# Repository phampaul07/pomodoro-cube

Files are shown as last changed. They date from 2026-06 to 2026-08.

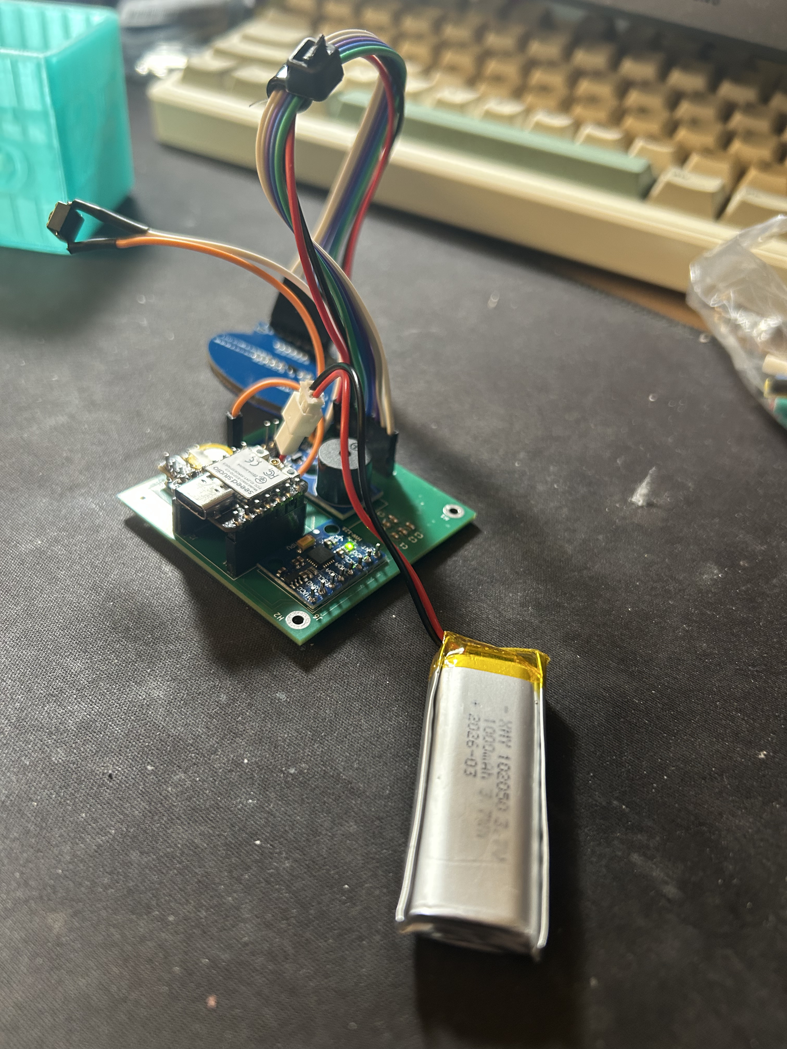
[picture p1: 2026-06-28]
images/components.jpg

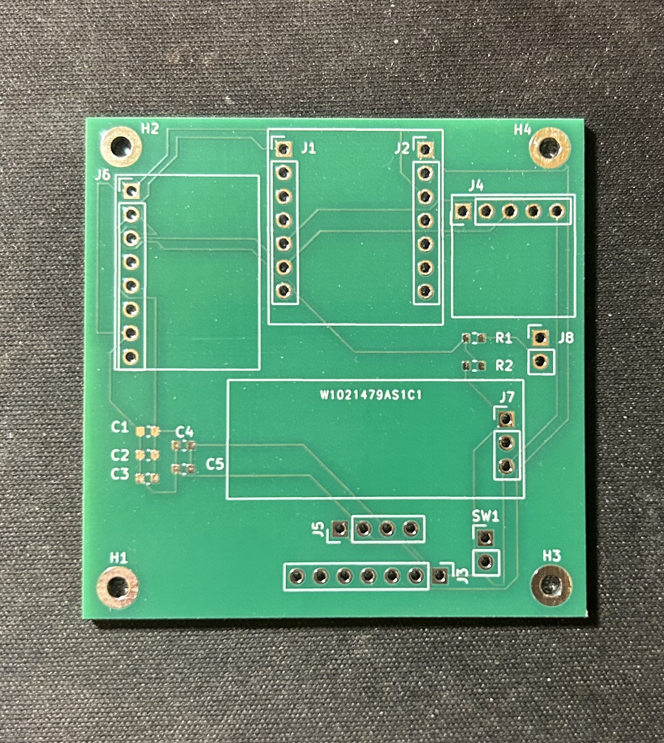
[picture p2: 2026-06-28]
images/front_pcb.jpg

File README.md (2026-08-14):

<h1 align="center"> Smart Pomodoro Cube</h1>

<h3 align="center">
A fully custom embedded productivity cube featuring a Pomodoro timer, digital clock, virtual pet, productivity tracker, and magnetic charging dock.
</h3>

<p align="center">
CircuitPython • ESP32-C3 • Embedded Systems • CAD • 3D Printing • Analog Electronics • KiCad
</p>

<p align="center">
  
</p>

---

# README Contents
- [Overview](#overview)
- [Demonstrations](#demonstrations)
- [Features](#features)
- [Hardware](#hardware)
- [Getting Started](#getting-started)
- [Mechanical Design](#mechanical-design)
- [Engineering Deep Dive](#engineering-deep-dive)
- [Software Highlights](#software-highlights)
- [Challenges](#challenges)
- [Lessons Learned](#lessons-learned)
- [Future Improvements](#future-improvements)
- [Gallery](#gallery)
- [Acknowledgements](#acknowledgements)
- [Contact](#contact)

---

# Overview

The Smart Pomodoro Cube is a handheld productivity device that combines embedded systems, hardware engineering, and industrial design into a compact form factor no larger than a standard Rubik's Cube.

Instead of navigating through menus or using a touchscreen, the cube uses its physical orientation to select timer durations. Once docked onto its custom magnetic charging station, it transforms into an entirely different interface featuring an interactive virtual pet, productivity tracker, and quick-access study tools.

Every major component—including the enclosure, charging dock, firmware, custom KiCad PCB, and user interface—was designed specifically for this project.

The goal was not only to create a useful studying companion, but also to explore embedded systems, custom electronics, CAD, and hardware-software integration while fitting everything inside an extremely limited volume.

---

# Demonstrations

The Pomodoro Cube has two primary modes of operation.

---

## Standalone Cube

<p align="center">
<a href="https://youtube.com/shorts/b-1S72bGzG8?feature=share">

</a>
</p>

<p align="center">
<b>Click the thumbnail above to watch the standalone demonstration.</b>
</p>

### Demonstrated Features

- Real-time clock
- Battery percentage
- Temperature monitoring
- Cube orientation timer selection
- Pause / Resume
- Timer reset
- Countdown progress bar
- Portable battery operation

---

## Interactive Charging Dock

<p align="center">
<a href="https://youtube.com/shorts/HYNcFR9NDS4?feature=share">

</a>
</p>

<p align="center">
<b>Click the thumbnail above to watch the dock demonstration.</b>
</p>

### Demonstrated Features

- Magnetic docking
- Automatic dock detection
- Charging indicator
- Clock Mode
- 15-minute Quick Timer
- Interactive Tamagotchi Pet
- Petting animation
- Productivity Stats

---

# Features

## Digital Clock

When idle, the cube functions as a portable desk clock displaying:

- Current time
- Battery percentage
- Temperature
- Charging status

using an external RTC module and onboard sensors.

---

## Pomodoro Timer

The cube's primary function is a distraction-free Pomodoro timer.

Simply rotate the cube onto one of its faces to instantly choose a timer duration.

Features include:

- Multiple timer durations
- Pause / Resume
- Reset
- Bar progress visualization
- Completion notification via beeps
- Battery-powered portability

---

## Magnetic Charging Dock

One of the biggest design goals was eliminating cables during normal use.

The cube charges magnetically using pogo pins while simultaneously detecting dock states and reading dock button presses. 

The charging dock was hand-built using a custom perfboard and soldered circuitry, while the internal electronics of the cube itself are mounted on a custom-designed PCB routed in KiCad.

---

## Dock Modes

Docking the cube unlocks four additional operating modes.

### Clock

Displays the standard clock while charging.

---

### Quick Timer

Instantly adds study time in 15-minute increments without rotating the cube.

---

### Tamagotchi

An interactive Tamagotchi-inspired virtual pet.

Features include:

- Idle animations
- Random blinking
- Petting animation
- Smooth sprite animation
- Physical interaction using dock buttons

---

### Productivity Statistics

Tracks long-term study habits including:

- Daily focus time
- Focus sessions
- Daily streak
- Lifetime sessions

---

# Hardware

| Component | Purpose |
|---|---|
| Seeed Studio XIAO ESP32-C3 | Main Microcontroller |
| Custom KiCad PCB | Main Board / Cube Electronics |
| 1.28" Round GC9A01 IPS Display | User Interface |
| MPU6050 | Orientation Detection |
| RTC Module | Timekeeping |
| 3.7V LiPo Battery | Portable Power |
| Magnetic Pogo Pins | Charging & Communication |
| Custom Perfboard | Dock Electronics |

---

# Getting Started

This runs on CircuitPython rather than compiled firmware, so there's no build/flash toolchain — the board mounts as a USB drive and files are copied directly onto it.

1. Flash the [CircuitPython UF2](https://circuitpython.org/board/seeed_xiao_esp32c3/) for the Seeed Studio XIAO ESP32-C3 (hold BOOT while plugging in, drag the `.uf2` onto the `ESP32C3` drive).
2. Once it reboots into CircuitPython, it'll appear as a `CIRCUITPY` drive. Copy the entire `firmware/` folder's contents onto it: `code.py`, `animation.py`, `dock.py`, the `.bmp` sprite assets, and the `lib/` folder of vendored Adafruit libraries.
3. `code.py` is the entry point — CircuitPython auto-runs it on boot. `firmware/legacy/standalone_cube.py` is an earlier, dock-less iteration kept for reference only; it isn't used.
4. The board reloads automatically any time `code.py` is saved. [Thonny](https://thonny.org/) (or any serial-capable editor) works well for live editing and viewing the serial console.

---

# Mechanical Design

A major objective of this project was fitting an entire embedded system inside the volume of a standard Rubik's Cube.

This required careful consideration of:

- Internal component placement
- Custom PCB dimensions and mounting
- Cable routing
- Battery placement
- Display clearance
- Magnet positioning
- Dock alignment

---

# Engineering Deep Dive

## Analog Button Multiplexing

Because the magnetic pogo pin interface between the cube and the dock only has four physical connections (5V, GND, 3.3V, and a single data line), it was physically impossible to dedicate separate GPIO pins for each of the four dock buttons.

To overcome this hardware constraint, every dock interaction is transmitted through the single available analog pin using a resistor ladder. Each button routes current through a different resistor, producing a unique voltage.

The ESP32 reads this incoming voltage through its ADC and determines which button was pressed based on predefined threshold ranges.

```
Button 1 → Home Clock
Button 2 → Quick Timer
Button 3 → Tomo
Button 4 → Productivity Stats
```

---

## Battery Monitoring

A fully charged LiPo battery outputs approximately 4.2V, exceeding the ESP32's safe analog input voltage.

To safely monitor the battery, a voltage divider using two identical 10kΩ resistors cuts the voltage in half before it reaches the ADC.

Hardware Flow:
```
Battery
↓
Voltage Divider
↓
ESP32 ADC
```

Software Logic:
```
ADC Reading
↓
Measured Voltage
↓
×2
↓
Actual Battery Voltage
↓
Battery Percentage
```

This approach allows safe and accurate battery monitoring without risking damage to the microcontroller.



---

## Firmware Architecture

The firmware is built around a finite state machine.

```
Standalone
 └── Clock
      │
      ▼
    Timer

Docked
 └── Clock
      ├── Quick Timer
      ├── Tomo
      └── Productivity Stats
```

Separating functionality into individual states simplified transitions, animations, and memory management.

---

# Software Highlights

- CircuitPython firmware
- SPI-driven GC9A01 display
- TileGrid sprite animations
- Memory-efficient bitmap loading
- Real-time battery monitoring
- Dock state detection
- ADC signal filtering
- Finite State Machine architecture

---

# Challenges

This project introduced me to several engineering disciplines simultaneously.

## Mechanical

- First complete CAD enclosure
- Designing around extremely limited internal space
- Dock alignment tolerances

---

## Electrical

- Designing a custom PCB in KiCad for the cube's internal layout
- Designing analog resistor ladder circuits
- Designing a voltage divider
- Magnetic pogo-pin charging
- Battery management
- Dock signal integrity

---

## Embedded Software

- Memory optimization
- Bitmap management
- Animation timing
- Display flickering
- ADC calibration
- State machine architecture

---

## Debugging

Some of the most time-consuming issues included:

- ESP32 memory limitations
- Magnetic charging reliability
- Analog threshold calibration
- Battery percentage accuracy
- Dock signal filtering
- Sprite memory fragmentation

Many of these required custom diagnostic firmware, multimeter testing, and extensive trial-and-error before arriving at stable solutions.

---

# Lessons Learned

This project taught me far more than simply building a productivity timer.

Some of the biggest skills I developed include:

- Embedded Systems
- CircuitPython
- Analog Circuit Design
- PCB Design (KiCad)
- Hardware Debugging
- CAD
- 3D Printing
- Battery Management
- SPI Displays
- Embedded UI Design
- Firmware Optimization
- State Machine Architecture

---

# Future Improvements

Although the current prototype is fully functional, there are several improvements I would like to explore.

- Custom PCB for the charging dock to replace the perfboard prototype
- Improved magnetic charging reliability
- Lower-power sleep mode
- Configurable timer durations
- Improved charging dock alignment
- Historical productivity graphs
- Rotating screen animation to make the interface fixed

---

# Gallery

| Cube | Dock |
|---|---|
| |  |

| Real-Time Clock | Iterated Timer |
|---|---|
| |  |

| Tamagotchi | Stats |
|---|---|
| | |

| PCB | Wiring |
|---|---|
| front_pcb | components|

---

# Acknowledgements

This project was independently designed and built using CircuitPython on the Seeed Studio XIAO ESP32-C3.

It combines concepts from embedded systems, analog electronics, firmware development, mechanical design, PCB design, and human-centered interaction into a single portable productivity device.

---

# Contact

- **Paul Pham** — [phampp07@gmail.com](mailto:phampp07@gmail.com) • [linkedin.com/in/paul-pham07](https://www.linkedin.com/in/paul-pham07)

---

## If you enjoyed this project, consider leaving a star!

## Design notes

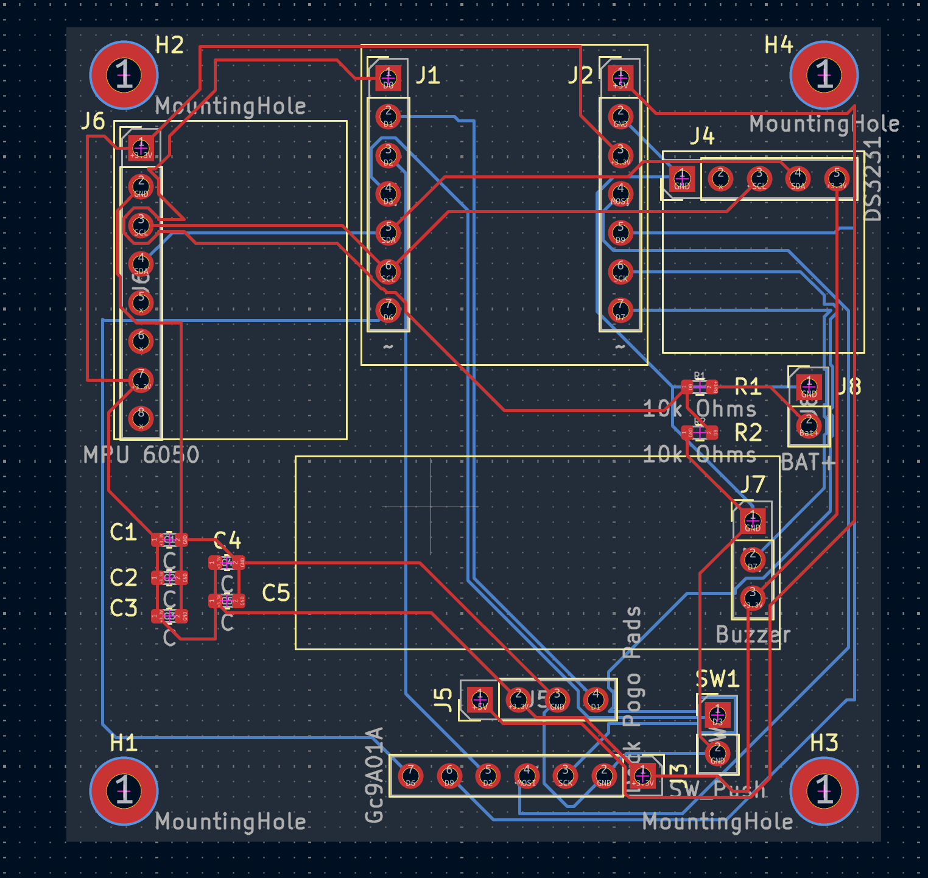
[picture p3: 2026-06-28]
images/hardware_design/pomodoro_pcb.png

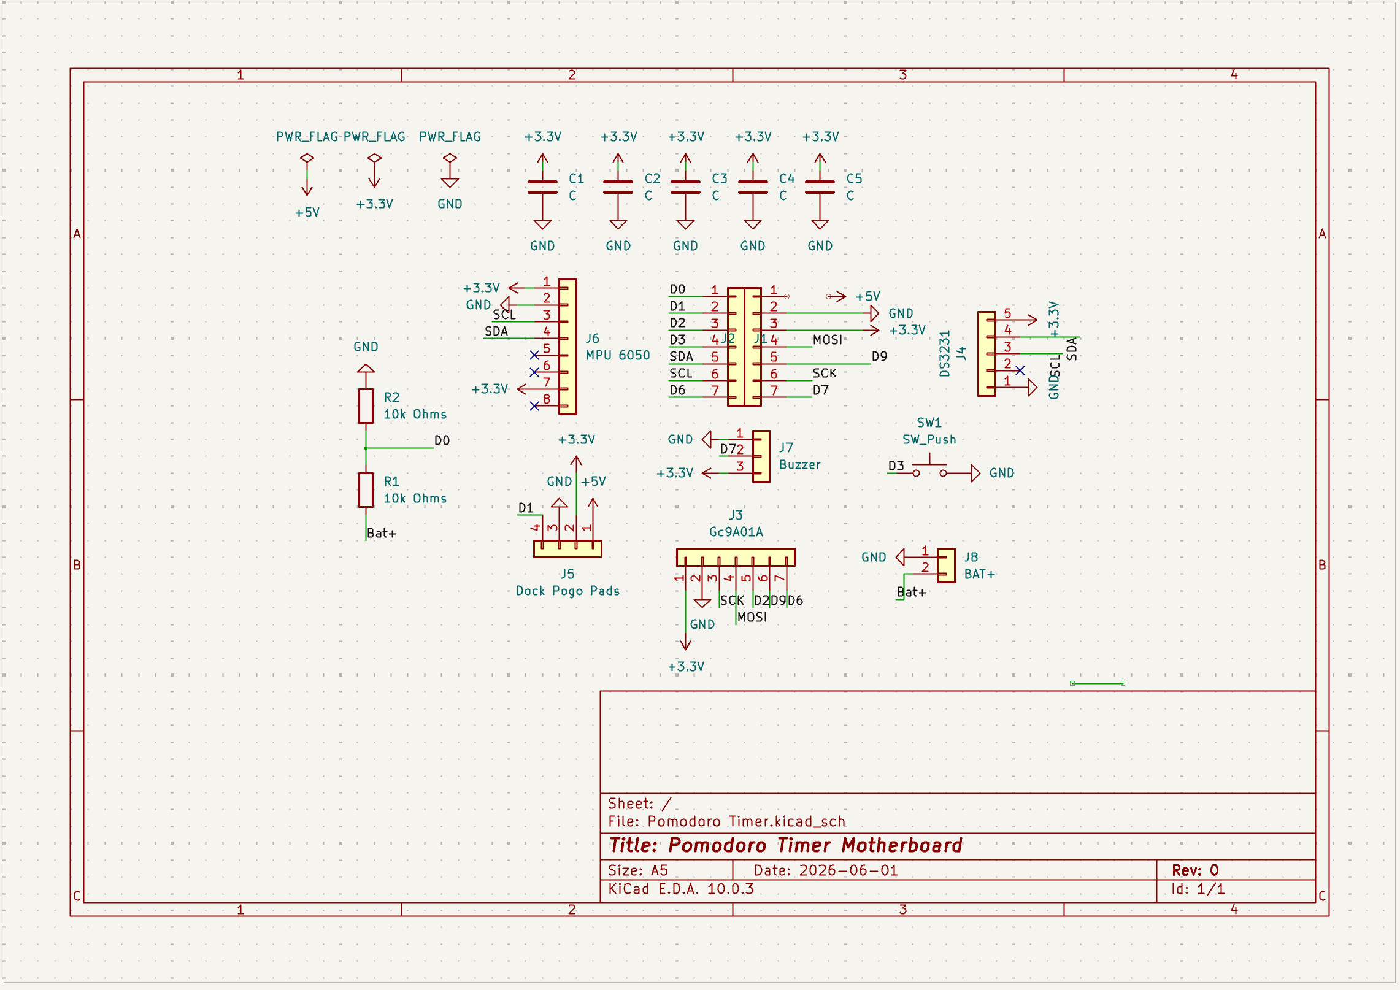
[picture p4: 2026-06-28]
images/hardware_design/pomodoro_schematic.png

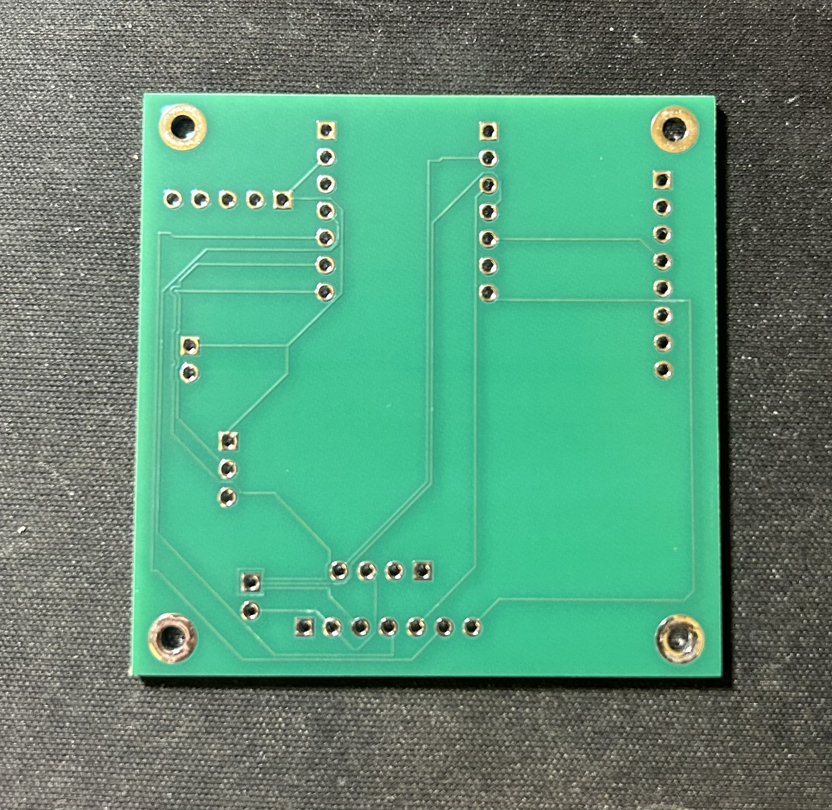
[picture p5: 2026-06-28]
images/back_pcb.jpg

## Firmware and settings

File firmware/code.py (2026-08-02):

import time
import board
import busio
import adafruit_mpu6050
import adafruit_ds3231
import digitalio
import terminalio
import displayio
import analogio
import fourwire
import alarm
import gc
import random
import microcontroller
import struct
from adafruit_gc9a01a import GC9A01A
from adafruit_display_text import label
from adafruit_display_shapes.rect import Rect
from adafruit_display_shapes.circle import Circle

# ------------------------------------------------------------
# 1. HARDWARE SETUP & INITIALIZATION
# ------------------------------------------------------------
FourWire = fourwire.FourWire
displayio.release_displays()

spi = busio.SPI(clock=board.D8, MOSI=board.D10)
battery_pin = analogio.AnalogIn(board.A0)
dock_pin = analogio.AnalogIn(board.A1)

tft_dc = board.D2
tft_cs = board.D9
tft_rst = board.D6

display_bus = FourWire(spi, command=tft_dc, chip_select=tft_cs, reset=tft_rst, baudrate=20000000)
display = GC9A01A(display_bus, width=240, height=240)
display.auto_refresh = False

i2c = busio.I2C(board.D5, board.D4)
mpu = adafruit_mpu6050.MPU6050(i2c, address=0x69)
rtc = adafruit_ds3231.DS3231(i2c)

button = digitalio.DigitalInOut(board.D3)
button.direction = digitalio.Direction.INPUT
button.pull = digitalio.Pull.UP 

buzzer = digitalio.DigitalInOut(board.D7)
buzzer.direction = digitalio.Direction.OUTPUT
buzzer.value = True

# ------------------------------------------------------------
# 2. STATE MEMORY VARIABLES
# ------------------------------------------------------------
mode_0 = "idle"
mode_1 = "5 minutes"
mode_2 = "25 minutes"
mode_3 = "45 minutes"
mode_4 = "60 minutes"
mode_5 = "finished"
mode_6 = "paused"
mode_7 = "reset"

time_duration = {
    mode_1: 300,
    mode_2: 1500,
    mode_3: 2700,
    mode_4: 3600
}

DOCKED_STATES = {"home", "timer", "tomo", "button_4", "dock_idle"}
MAX_INCREMENT_SECONDS = 99 * 60 + 59

orientation_buffer = []
buffer_size = 6

mode = mode_0 
previous_mode = mode_0
previous_active_mode = mode_0

time_remaining = 0 
last_tick_time = 0
last_battery_tick = 0
battery_interval = 3
last_clock_tick = 0
CLOCK_INTERVAL = 1.0

alarm_active = False
alarm_step = 0
alarm_next_time = 0
finished_from_mode = None
ALARM_GAP = 1.0
ALARM_ON_TIME = 0.12
ALARM_OFF_TIME = 0.13
ALARM_BEEPS_PER_BURST = 3
reset_release_required = False

was_docked = False
last_dock_state = "none"
current_timer_max = 900

# Dock stability / power-saving state
last_valid_dock_state = "none"
last_valid_dock_time = 0
DOCK_LOSS_GRACE = 0.40

last_display_refresh = 0
DOCKED_REFRESH_INTERVAL = 0.05
UNDOCKED_REFRESH_INTERVAL = 0.01

# Screen Management
current_screen = "clock"

# Focus tracker state, stored in microcontroller.nvm.
FOCUS_MAGIC = b"FCS1"
FOCUS_FORMAT = "<4sHBBHHHII"
FOCUS_RECORD_SIZE = 22

focus_year = 0
focus_month = 0
focus_day = 0
focus_streak = 0
focus_sessions_today = 0
focus_minutes_today = 0
focus_total_sessions = 0
focus_total_minutes = 0

# Petting & Idle Variables
is_petting = False
tomo_press_start_time = 0
pet_frame_index = 0
pet_start_time = 0
pet_sequence = (4, 0, 1, 2, 3)

idle_wait_time = 2.0
last_idle_action_time = 0

anim_frames = []
anim_durations = []
anim_index = 0
anim_next_time = 0

frames = [
    "/Tomo1.bmp",
    "/Tomo2.bmp",
    "/Tomo3.bmp",
    "/Tomo4.bmp",
    "/Tomo5.bmp",
    "/Tomo6.bmp",
    "/Tomo7.bmp",
    "/Tomo8.bmp"
]

# ------------------------------------------------------------
# 3. HELPER FUNCTIONS
# ------------------------------------------------------------
def is_leap_year(year):
    return year % 4 == 0 and (year % 100 != 0 or year % 400 == 0)


def date_ordinal(year, month, day):
    month_days = (31, 28, 31, 30, 31, 30, 31, 31, 30, 31, 30, 31)
    total = 365 * (year - 1)
    total += (year - 1) // 4
    total -= (year - 1) // 100
    total += (year - 1) // 400
    for index in range(month - 1):
        total += month_days[index]
    if month > 2 and is_leap_year(year):
        total += 1
    return total + day


def load_focus_data():
    global focus_year, focus_month, focus_day
    global focus_streak, focus_sessions_today, focus_minutes_today
    global focus_total_sessions, focus_total_minutes
    try:
        nvm = microcontroller.nvm
        if nvm is None or len(nvm) < FOCUS_RECORD_SIZE:
            return
        stored = bytes(nvm[0:FOCUS_RECORD_SIZE])
        values = struct.unpack(FOCUS_FORMAT, stored)
        if values[0] != FOCUS_MAGIC:
            return
        (_, focus_year, focus_month, focus_day, focus_streak,
         focus_sessions_today, focus_minutes_today,
         focus_total_sessions, focus_total_minutes) = values
    except Exception as error:
        print("Focus data load error:", error)


def save_focus_data():
    try:
        nvm = microcontroller.nvm
        if nvm is None or len(nvm) < FOCUS_RECORD_SIZE:
            return
        packed = struct.pack(
            FOCUS_FORMAT,
            FOCUS_MAGIC,
            focus_year,
            focus_month,
            focus_day,
            focus_streak,
            focus_sessions_today,
            focus_minutes_today,
            focus_total_sessions,
            focus_total_minutes,
        )
        nvm[0:FOCUS_RECORD_SIZE] = packed
    except Exception as error:
        print("Focus data save error:", error)


def update_focus_display():
    try:
        focus_today_value.text = str(focus_sessions_today)
        focus_minutes_value.text = str(focus_minutes_today) + " min"
        focus_streak_value.text = str(focus_streak) + " days"
        focus_total_value.text = str(focus_total_sessions)
    except Exception:
        pass


def record_focus_session(duration_seconds):
    global focus_year, focus_month, focus_day
    global focus_streak, focus_sessions_today, focus_minutes_today
    global focus_total_sessions, focus_total_minutes
    try:
        now = rtc.datetime
        year = now.tm_year
        month = now.tm_mon
        day = now.tm_mday
    except Exception as error:
        print("RTC focus error:", error)
        return
    minutes = max(1, int(duration_seconds // 60))
    if focus_year == year and focus_month == month and focus_day == day:
        focus_sessions_today += 1
        focus_minutes_today += minutes
    else:
        if focus_year > 0:
            previous_day = date_ordinal(focus_year, focus_month, focus_day)
            current_day = date_ordinal(year, month, day)
            focus_streak = focus_streak + 1 if current_day - previous_day == 1 else 1
        else:
            focus_streak = 1
        focus_year = year
        focus_month = month
        focus_day = day
        focus_sessions_today = 1
        focus_minutes_today = minutes
    focus_total_sessions += 1
    focus_total_minutes += minutes
    save_focus_data()
    update_focus_display()


def get_battery_percentage():
    raw_reading = battery_pin.value
    pin_voltage = (raw_reading / 65535.0) * 3.3
    real_battery_voltage = pin_voltage * 2.0 
    percentage = ((real_battery_voltage - 3.2) / (4.2 - 3.2)) * 100
    percentage = max(0, min(100, int(percentage)))
    return percentage, real_battery_voltage

def play_beep(duration):
    buzzer.value = False
    time.sleep(duration)
    buzzer.value = True
    time.sleep(0.1)

def stop_buzzer():
    buzzer.value = True

def start_finished_alarm():
    global alarm_active, alarm_step, alarm_next_time, finished_from_mode
    global mode, previous_mode, time_remaining, reset_release_required

    finished_from_mode = mode
    alarm_active = True
    alarm_step = 0
    alarm_next_time = time.monotonic()
    mode = mode_5
    previous_mode = mode_5
    time_remaining = 0
    reset_release_required = False
    orientation_buffer.clear()
    time_label.text = "00:00"

    while len(bar_fill_group) > 0:
        bar_fill_group.pop()

def stop_finished_alarm():
    global alarm_active, alarm_step, alarm_next_time, finished_from_mode
    alarm_active = False
    alarm_step = 0
    alarm_next_time = 0
    stop_buzzer()

def reset_timer_state():
    global mode, previous_mode, previous_active_mode
    global time_remaining, current_timer_max, last_tick_time
    global reset_release_required

    stop_finished_alarm()
    mode = mode_7
    previous_mode = mode_7
    previous_active_mode = mode_0
    time_remaining = 0
    current_timer_max = 900
    last_tick_time = time.monotonic()
    reset_release_required = True
    orientation_buffer.clear()

    pause_string.hidden = True
    pause_bar_1.hidden = True
    pause_bar_2.hidden = True
    time_label.y = 110
    bar_outline.y = 145
    bar_fill_group.y = 0
    time_label.text = "00:00"

    while len(bar_fill_group) > 0:
        bar_fill_group.pop()

def handle_finished_orientation(detected):
    global mode, previous_mode, previous_active_mode
    global time_remaining, current_timer_max, last_tick_time
    global reset_release_required, finished_from_mode

    if detected is None or detected == "unknown":
        return False

    # Ignore the same face that started the timer which just finished.
    # The alarm keeps repeating until the cube is moved to a different state.
    if detected == finished_from_mode or detected == mode_5:
        return False

    stop_finished_alarm()
    orientation_buffer.clear()
    reset_release_required = True

    pause_string.hidden = True
    pause_bar_1.hidden = True
    pause_bar_2.hidden = True
    time_label.y = 110
    bar_outline.y = 145
    bar_fill_group.y = 0

    while len(bar_fill_group) > 0:
        bar_fill_group.pop()

    if detected in time_duration:
        mode = detected
        previous_mode = detected
        previous_active_mode = detected
        time_remaining = time_duration[detected]
        current_timer_max = time_duration[detected]
        last_tick_time = time.monotonic()

        minutes = time_remaining // 60
        seconds = time_remaining % 60
        time_label.text = f"{minutes:02d}:{seconds:02d}"
        bar_fill_group.append(Rect(21, 147, 198, 16, fill=0xffffff))

        if detected == mode_1:
            display.rotation = 180
        elif detected == mode_2:
            display.rotation = 90
        elif detected == mode_3:
            display.rotation = 0
        elif detected == mode_4:
            display.rotation = 270

    elif detected == mode_6:
        mode = mode_6
        previous_mode = mode_6
        previous_active_mode = mode_0
        time_remaining = 0
        current_timer_max = 900
        last_tick_time = time.monotonic()
        time_label.text = "00:00"
        pause_string.hidden = False
        pause_bar_1.hidden = False
        pause_bar_2.hidden = False
        time_label.y = 120
        bar_outline.y = 152
        bar_fill_group.y = 7

    elif detected == mode_7:
        reset_timer_state()

    else:
        return False

    finished_from_mode = None
    play_beep(0.1)
    return True

def update_finished_alarm(now):
    global alarm_step, alarm_next_time

    if not alarm_active or now < alarm_next_time:
        return

    if alarm_step < ALARM_BEEPS_PER_BURST * 2:
        if alarm_step % 2 == 0:
            buzzer.value = False
            alarm_next_time = now + ALARM_ON_TIME
        else:
            buzzer.value = True
            alarm_next_time = now + ALARM_OFF_TIME
        alarm_step += 1
    else:
        buzzer.value = True
        alarm_step = 0
        alarm_next_time = now + ALARM_GAP

def update_clock_display():
    clock_time = rtc.datetime
    hour_12 = clock_time.tm_hour % 12
    if hour_12 == 0: 
        hour_12 = 12
    time_str = f"{hour_12}:{clock_time.tm_min:02}"
    clock_label.text = time_str
    clock_label.x = (240 - len(time_str) * 36) // 2
    temp_c = rtc.temperature
    temp_f = (temp_c * 9/5) + 32
    calibrated_temp = temp_f - 13
    temp_string.text = str(int(calibrated_temp))

def auto_rotate():
    accel_x, accel_y, accel_z = mpu.acceleration
    if accel_z < -8.3 and abs(accel_x) < 6 and abs(accel_y) < 6: 
        display.rotation = 0
    elif accel_z > 8.3 and abs(accel_x) < 6 and abs(accel_y) < 6: 
        display.rotation = 180
    elif accel_x < -8.3 and abs(accel_y) < 6 and abs(accel_z) < 6: 
        display.rotation = 90
    elif accel_x > 8.3 and abs(accel_y) < 6 and abs(accel_z) < 6: 
        display.rotation = 270

def get_orientation():
    accel_x, accel_y, accel_z = mpu.acceleration

    abs_x = abs(accel_x)
    abs_y = abs(accel_y)
    abs_z = abs(accel_z)

    # Dominant-axis detection tolerates slight table or hand tilt.
    minimum_axis = 7.0
    dominance_margin = 1.5

    if (
        abs_z >= minimum_axis and
        abs_z >= abs_x + dominance_margin and
        abs_z >= abs_y + dominance_margin
    ):
        raw = mode_3 if accel_z < 0 else mode_1

    elif (
        abs_y >= minimum_axis and
        abs_y >= abs_x + dominance_margin and
        abs_y >= abs_z + dominance_margin
    ):
        raw = mode_6 if accel_y < 0 else mode_7

    elif (
        abs_x >= minimum_axis and
        abs_x >= abs_y + dominance_margin and
        abs_x >= abs_z + dominance_margin
    ):
        raw = mode_2 if accel_x < 0 else mode_4

    else:
        raw = "unknown"

    orientation_buffer.append(raw)

    if len(orientation_buffer) > buffer_size:
        orientation_buffer.pop(0)

    if (
        len(orientation_buffer) == buffer_size and
        len(set(orientation_buffer)) == 1
    ):
        return orientation_buffer[0]

    return None

def check_dock():
    total = 0

    # More averaging helps with USB power and contact noise.
    for _ in range(16):
        total += dock_pin.value
        time.sleep(0.0015)

    raw_val = total / 16

    # Uncomment temporarily to recalibrate after hardware changes:
    # print("Dock ADC:", raw_val)

    # Specific dock buttons.
    if raw_val >= 45000:
        return "home"
    elif 20000 <= raw_val <= 25000:
        return "timer"
    elif 15500 <= raw_val <= 19500:
        return "tomo"
    elif 13950 <= raw_val <= 14500:
        return "button_4"

    # The original dock circuit reports values above about 6000 whenever
    # physical dock contact exists. Keep the device in charging mode even
    # when voltage noise falls between the individual button windows.
    elif raw_val > 6000:
        return "dock_idle"

    return "none"


def get_stable_dock_state(now):
    global last_valid_dock_state, last_valid_dock_time

    detected = check_dock()

    if detected != "none":
        last_valid_dock_state = detected
        last_valid_dock_time = now
        return detected

    # Ignore very brief dropouts caused by USB/contact noise.
    if now - last_valid_dock_time <= DOCK_LOSS_GRACE:
        return last_valid_dock_state

    last_valid_dock_state = "none"
    return "none"

def show_docked_battery_ui():
    percent_label.hidden = True
    image_batcharge_tile.hidden = False
    battery_outline.hidden = True
    battery_tip.hidden = True

    for cell in battery_cells:
        cell.hidden = True

def show_undocked_battery_ui():
    image_batcharge_tile.hidden = True
    battery_outline.hidden = False
    battery_tip.hidden = False

def safe_get_orientation():
    try:
        return get_orientation()
    except Exception as error:
        print("MPU read error:", error)
        return None

def safe_check_dock(now):
    try:
        return get_stable_dock_state(now)
    except Exception as error:
        print("Dock read error:", error)
        return "none"

def safe_update_clock():
    try:
        update_clock_display()
    except Exception as error:
        print("RTC read error:", error)

def safe_auto_rotate():
    try:
        auto_rotate()
    except Exception as error:
        print("MPU rotate error:", error)

def start_idle_animation(frame_sequence, duration_sequence):
    global anim_frames, anim_durations
    global anim_index, anim_next_time, last_idle_action_time

    if not frame_sequence:
        return

    anim_frames = list(frame_sequence)
    anim_durations = list(duration_sequence)

    if len(anim_durations) < len(anim_frames):
        default_duration = (
            anim_durations[-1] if anim_durations else 0.1
        )
        while len(anim_durations) < len(anim_frames):
            anim_durations.append(default_duration)

    anim_index = 0
    set_idle_frame(anim_frames[0])
    anim_next_time = time.monotonic() + anim_durations[0]
    last_idle_action_time = time.monotonic()


def update_idle_animation(now):
    global anim_frames, anim_durations
    global anim_index, anim_next_time, last_idle_action_time

    if not anim_frames:
        return

    if now < anim_next_time:
        return

    anim_index += 1

    if anim_index >= len(anim_frames):
        anim_frames = []
        anim_durations = []
        anim_index = 0
        anim_next_time = 0
        set_idle_frame(0)
        last_idle_action_time = now
        return

    set_idle_frame(anim_frames[anim_index])
    anim_next_time = now + anim_durations[anim_index]


def set_idle_frame(frame_index):
    gc.collect()
    new_bmp = displayio.OnDiskBitmap(frames[frame_index])
    idle_tg.bitmap = new_bmp
    idle_tg.pixel_shader = new_bmp.pixel_shader

def group_contains(group, item):
    for child in group:
        if child is item:
            return True
    return False

def safe_remove(group, item):
    if group_contains(group, item):
        group.remove(item)

def switch_screen(new_screen):
    global current_screen, current_ui, mode, previous_mode
    global previous_active_mode, reset_release_required

    if current_screen == new_screen:
        return

    safe_remove(master_group, current_ui)

    if new_screen == "clock":
        current_ui = Idle_UI
        mode = mode_0
        previous_mode = mode_0
        previous_active_mode = mode_0
        reset_release_required = False
        orientation_buffer.clear()

    elif new_screen == "timer":
        current_ui = Timer_UI

        # Enter timer mode with clean state so returning from idle while
        # resting on the same face still restarts that timer.
        if not alarm_active:
            mode = mode_0
            previous_mode = mode_0
            previous_active_mode = mode_0
            reset_release_required = False
            orientation_buffer.clear()

    elif new_screen == "tomo":
        current_ui = Tomo_UI
        mode = mode_0
        previous_mode = mode_0
        previous_active_mode = mode_0
        reset_release_required = False
        orientation_buffer.clear()

    elif new_screen == "focus":
        current_ui = Focus_UI
        mode = mode_0
        previous_mode = mode_0
        previous_active_mode = mode_0
        reset_release_required = False
        orientation_buffer.clear()
        update_focus_display()

    else:
        return

    master_group.append(current_ui)
    current_screen = new_screen
    display.rotation = 0

# ------------------------------------------------------------
# 4. UI LAYER GENERATION
# ------------------------------------------------------------
master_group = displayio.Group()
display.root_group = master_group

# Global Elements wrapped in Groups for safety
circle_group = displayio.Group()
master_group.append(circle_group)

global_circle = Circle(120, 120, 117, outline=0xFFFFFF)
circle_group.append(global_circle)

battery_group = displayio.Group()
master_group.append(battery_group)

percent_label = label.Label(terminalio.FONT, text="67%", color=0xFFFFFF, x=111, y=185)
battery_group.append(percent_label)

batcharge_bitmap = displayio.OnDiskBitmap("/Battery_Charge.bmp")
image_batcharge_tile = displayio.TileGrid(batcharge_bitmap, pixel_shader=batcharge_bitmap.pixel_shader, x=95, y=193)
image_batcharge_tile.hidden = True
battery_group.append(image_batcharge_tile)

battery_outline = Rect(95, 193, 48, 18, outline=0xFFFFFF)
battery_tip = Rect(143, 197, 2, 10, fill=0xFFFFFF, outline=0xFFFFFF)
battery_group.append(battery_outline)
battery_group.append(battery_tip)

battery_cells = [
    Rect(97, 195, 8, 14, fill=0x4caf50, outline=0x4caf50),
    Rect(106, 195, 8, 14, fill=0x4caf50, outline=0x4caf50),
    Rect(115, 195, 8, 14, fill=0x4caf50, outline=0x4caf50),
    Rect(124, 195, 8, 14, fill=0x4caf50, outline=0x4caf50),
    Rect(133, 195, 8, 14, fill=0x4caf50, outline=0x4caf50)
]

for cell in battery_cells:
    battery_group.append(cell)

# ---- SCREEN 1: CLOCK UI ----
Idle_UI = displayio.Group()
clock_label = label.Label(terminalio.FONT, text="00:00", color=0xFFFFFF, x=30, y=125, scale=6)
Idle_UI.append(clock_label)

thermometer_bitmap = displayio.OnDiskBitmap("/thermometer.bmp")
image_thermometer_tile = displayio.TileGrid(thermometer_bitmap, pixel_shader=thermometer_bitmap.pixel_shader, x=74, y=45)
Idle_UI.append(image_thermometer_tile)

temperature_bitmap = displayio.OnDiskBitmap("/temperature.bmp")
image_temperature_tile = displayio.TileGrid(temperature_bitmap, pixel_shader=temperature_bitmap.pixel_shader, x=135, y=39)
Idle_UI.append(image_temperature_tile)

temp_string = label.Label(terminalio.FONT, text="0", color=0xFFFFFF, x=101, y=62, scale=3)
Idle_UI.append(temp_string)

# ---- SCREEN 2: TIMER UI ----
Timer_UI = displayio.Group()
time_label = label.Label(terminalio.FONT, text="00:00", color=0xFFFFFF, x=30, y=110, scale=6)
Timer_UI.append(time_label)

bar_outline = Rect(19, 145, 202, 20, outline=0xffffff)
Timer_UI.append(bar_outline)

bar_fill_group = displayio.Group()
Timer_UI.append(bar_fill_group)
bar_fill_group.append(Rect(21, 147, 198, 16, fill=0xffffff))

pause_bar_1 = Rect(124, 22, 9, 29, fill=0xffffff, outline=0xffffff)
pause_bar_1.hidden = True
pause_bar_2 = Rect(107, 22, 9, 29, fill=0xffffff, outline=0xffffff)
pause_bar_2.hidden = True

pause_string = label.Label(terminalio.FONT, text="Paused...", color=0xFFFFFF, x=79, y=77, scale=2)
pause_string.hidden = True

Timer_UI.append(pause_bar_1)
Timer_UI.append(pause_bar_2)
Timer_UI.append(pause_string)

# ---- SCREEN 3: TOMO UI ----
Tomo_UI = displayio.Group()
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

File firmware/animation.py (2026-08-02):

import board
import busio
import displayio
import fourwire
import time
import random
import gc
from adafruit_gc9a01a import GC9A01A

# 1. Release any existing displays
displayio.release_displays()

# 2. Set up the SPI bus EXACTLY like your main code
spi = busio.SPI(clock=board.D8, MOSI=board.D10)

tft_dc = board.D2
tft_cs = board.D9
tft_rst = board.D6 

# 3. Create the display bus and display object
FourWire = fourwire.FourWire
display_bus = FourWire(spi, command=tft_dc, chip_select=tft_cs, reset=tft_rst, baudrate=60000000)
display = GC9A01A(display_bus, width=240, height=240)

# 4. Create the main UI group
main_group = displayio.Group()
display.root_group = main_group

# 5. File paths for ALL 5 frames
frames = [
    "/Tomo1.bmp", # Index 0: Open
    "/Tomo2.bmp", # Index 1: Half
    "/Tomo3.bmp", # Index 2: Closed
    "/Tomo4.bmp", # Index 3: Left
    "/Tomo5.bmp"  # Index 4: Right
]

# 6. Initial Load (Eyes Open)
gc.collect()
bitmap = displayio.OnDiskBitmap(frames[0])

# 7. Wrap it in a TileGrid 
tile_grid = displayio.TileGrid(
    bitmap,
    pixel_shader=bitmap.pixel_shader,
    width=1,
    height=1,
    tile_width=bitmap.width,
    tile_height=bitmap.height
)

# 8. Center the image dynamically! 
tile_grid.x = (240 - bitmap.width) // 2
tile_grid.y = (240 - bitmap.height) // 2

# 9. Put it on the screen!
main_group.append(tile_grid)

# --- HELPER FUNCTION FOR MEMORY-SAFE SWAPPING ---
def set_frame(frame_index):
    gc.collect() # Clean up RAM before loading the new image
    new_bmp = displayio.OnDiskBitmap(frames[frame_index])
    tile_grid.bitmap = new_bmp
    tile_grid.pixel_shader = new_bmp.pixel_shader

# 10. The Idle Animation Loop
print("Tomo Idle Animation Running (Now with dancing)!")

while True:
    try:
        # Step A: Keep eyes open for a random amount of time (between 2 and 5 seconds)
        set_frame(0)
        time.sleep(random.uniform(2.0, 5.0))
        
        # Roll a 10-sided dice!
        dice_roll = random.randint(1, 10)
        
        # 20% Chance to Dance
        if dice_roll <= 2: 
            # The Dance Sequence (Loops 3 times)
            for _ in range(3):
                set_frame(3) # Left
                time.sleep(0.3)
                
                set_frame(1) # Half Closed
                time.sleep(0.3)
                
                set_frame(4) # Right
                time.sleep(0.3)
                
                set_frame(1) # Half Closed
                time.sleep(0.3)
                
        # 80% Chance to do a normal blink
        else:
            set_frame(1) # Half
            time.sleep(0.04) 
            
            set_frame(2) # Closed
            time.sleep(0.1)  
            
            set_frame(1) # Half
            time.sleep(0.04) 
        
    except MemoryError:
        # Just in case the ESP32 hiccups, catch it and reset the loop
        print("Memory collected, continuing animation...")
        gc.collect()
        time.sleep(0.5)

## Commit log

2026-08-03 Clarify project focus and add new feature
    Updated project description to specify a productivity timer and added a new feature about rotating screen animation.
2026-08-13 Fix broken hero image, resolve firmware entry point, add LICENSE and Getting Started
    [standalone_cube.py]
